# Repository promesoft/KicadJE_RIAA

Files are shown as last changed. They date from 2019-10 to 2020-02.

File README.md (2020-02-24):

# KicadJE_RIAA
RIAA apllifier test

# Status - RIAA installed in stereo setup
## Initial 
| Stage  | Detail | Status |
| --- | --- | --- |
| create material  | sch/pcb | OK  |
| | gerber | OK |
| production  | | OK |
|  | produced | OK |
|  | delivered | OK |
## Preliminary validation
| Test  | Detail | Status |
| --- | --- | --- |
| Initial Inspection | | Chose different RCA |
| Initial Technical Test |  | Different RCA does not match pins |
| Initial Product Test |  | Working - no hum |

## Secondary validation
| Test  | Detail | Status |
| --- | --- |--- |
| Product Test |  | |
| Product Test |  |  |
| Quality | | |
| Quality | | |
| Long Term Product Test |  |  |
| Power Draw |  | 

## Errata
### Errata -
1 - RCA footprint wrong (flip gnd and right)

2 - V-GND 2 does not have resistor balance - only LED indicator as input

3 - C107, C109, C111, C112 should either not be mounted or significantly smaller (10nF ?)

4 - U302B needs an 18k to GND on pin 5

## Issues and Notes
### 

# Pictures

# Inspiration

http://audio.engineeringvista.com/AudioKits/Phono-1/Design/Part6.htm

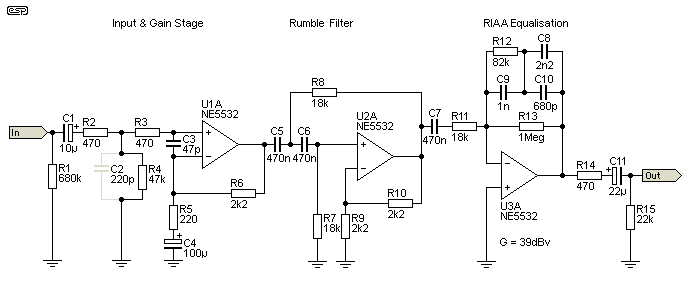
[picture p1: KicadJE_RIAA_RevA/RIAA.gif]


http://sound.whsites.net/project25.htm

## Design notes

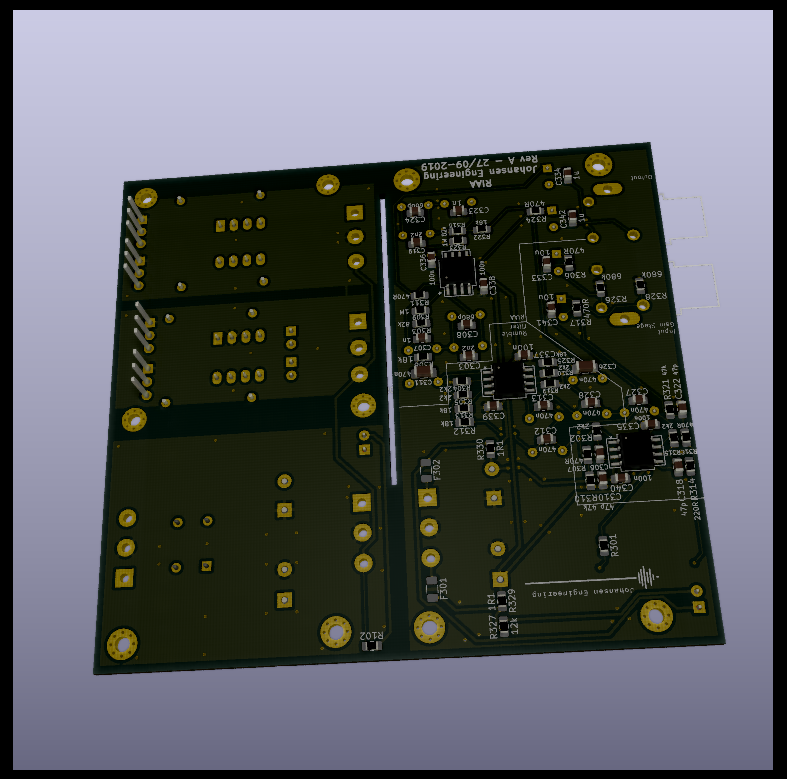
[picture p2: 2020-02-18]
KicadJE_RIAA_RevB/KicadJE_RIAA_bottom.png

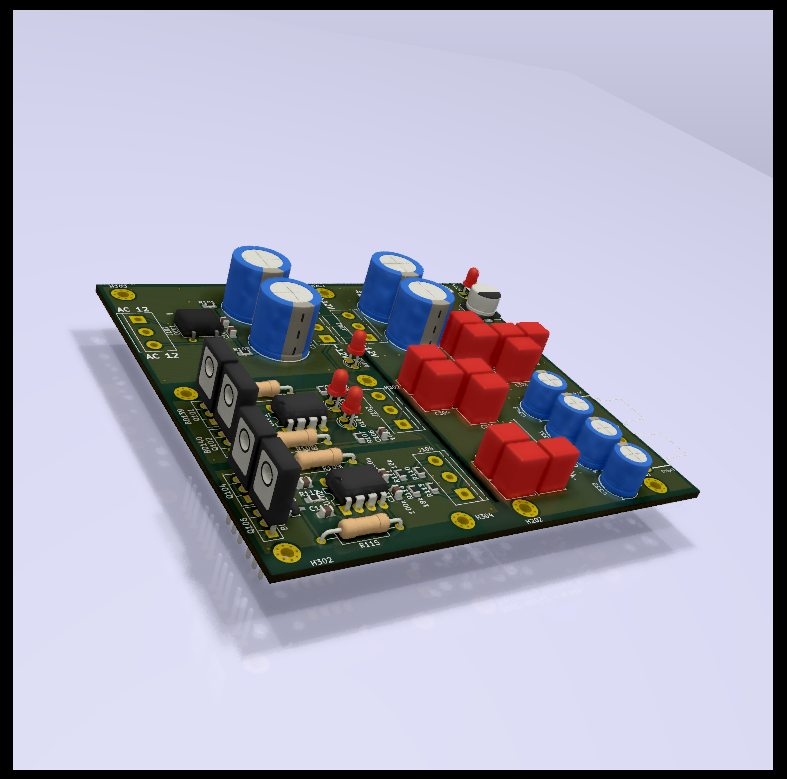
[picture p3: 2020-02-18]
KicadJE_RIAA_RevB/KicadJE_RIAA_top.png

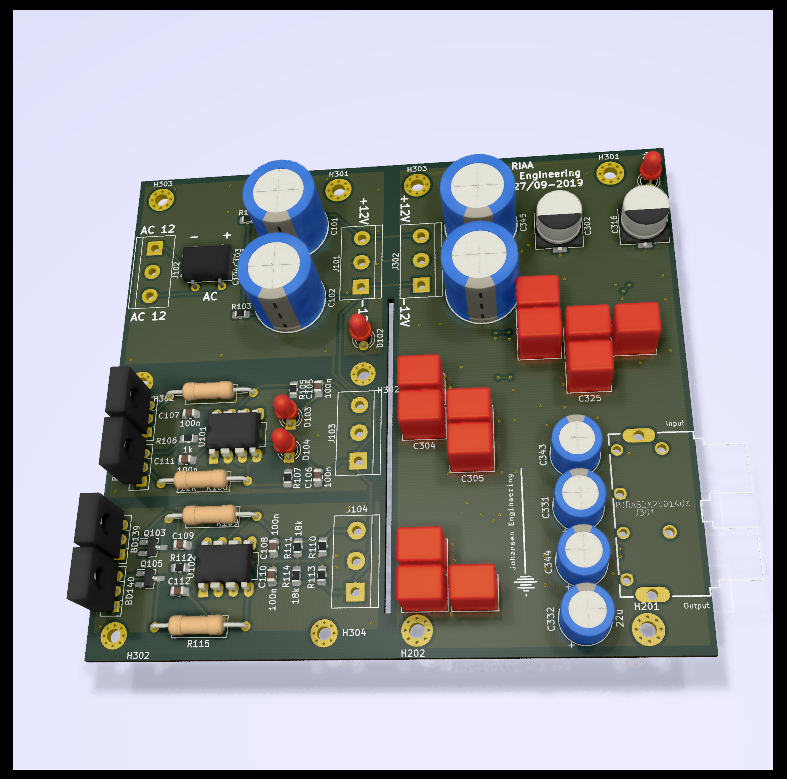
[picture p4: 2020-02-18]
KicadJE_RIAA_RevB/KicadJE_RIAA_top2.png

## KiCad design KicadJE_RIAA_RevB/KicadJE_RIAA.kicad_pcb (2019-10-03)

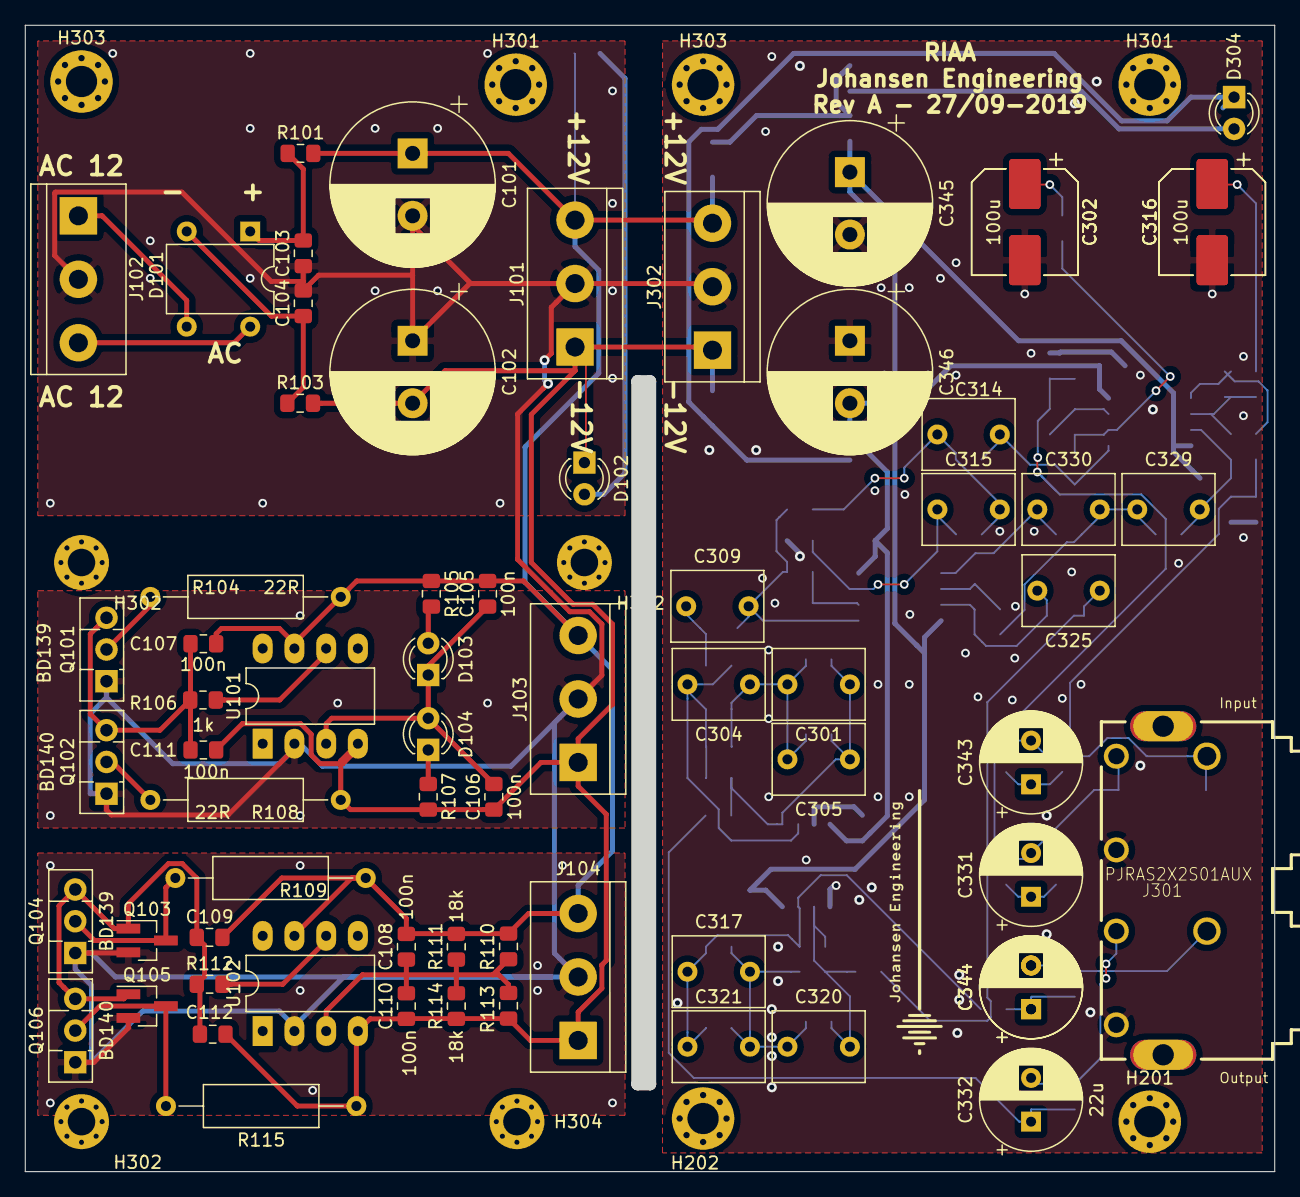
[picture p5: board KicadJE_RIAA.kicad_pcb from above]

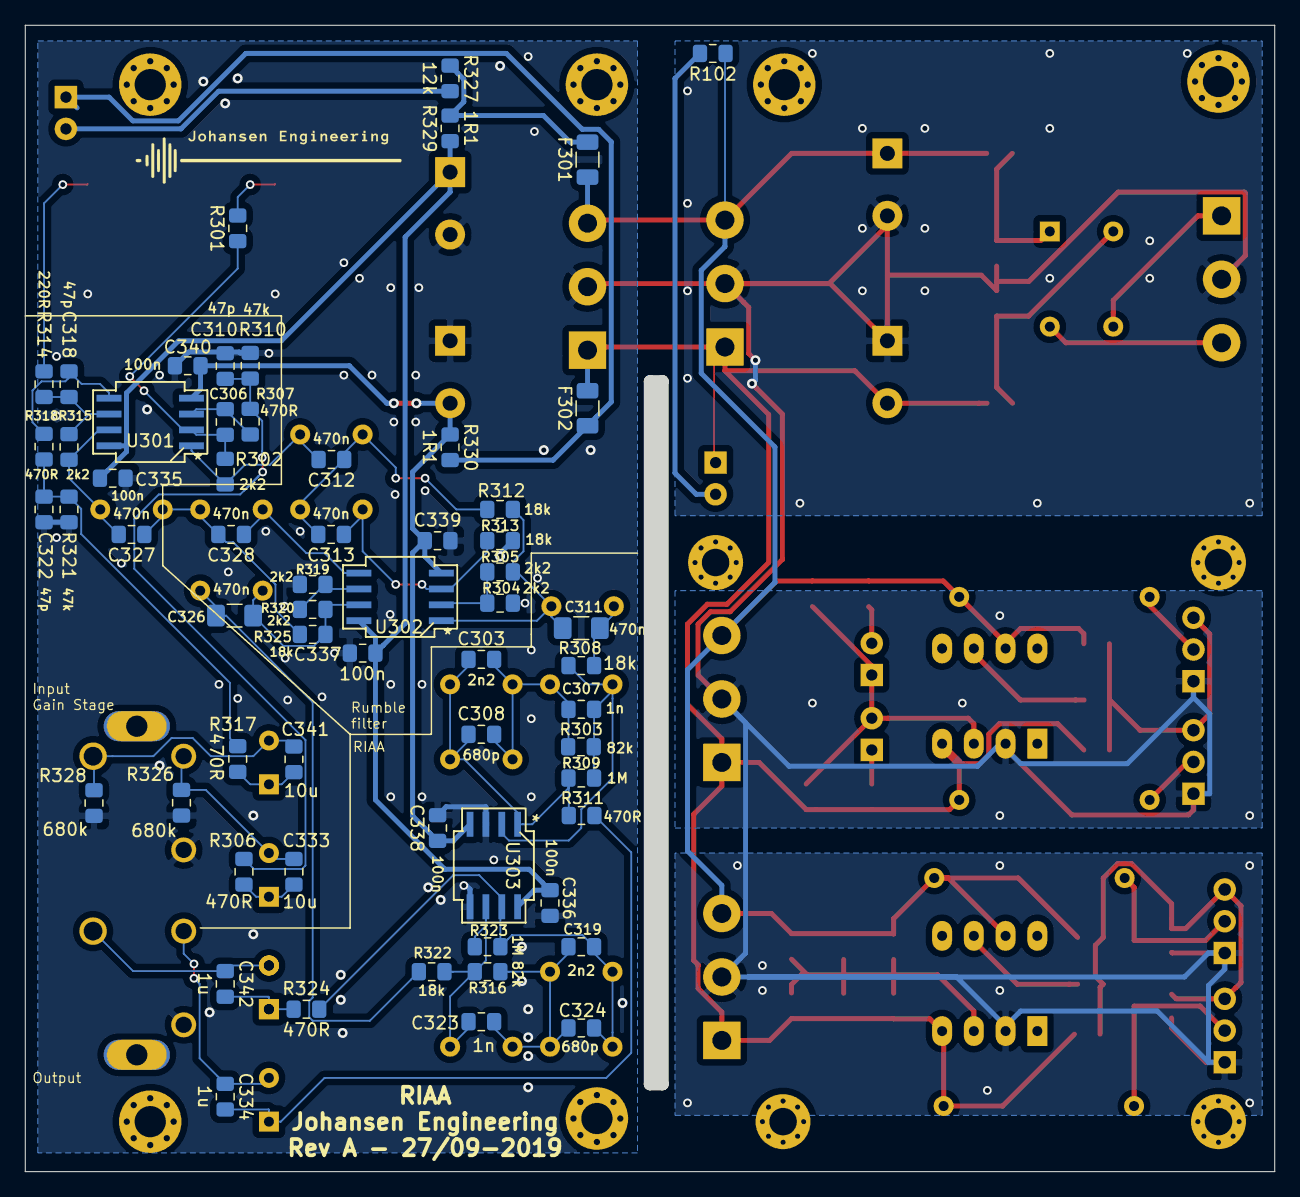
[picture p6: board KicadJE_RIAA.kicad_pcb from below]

Board: 2 copper layers, 100.0 x 91.8 mm, 140 parts (62 on the bottom side), 59 nets.

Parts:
C101, C102, C345, C346: 470u; CP_Radial_D13.0mm_P5.00mm
C103, C104, C105, C106, C107, C108, C109, C110, C111, C112, C335, C336, C337, C338, C339, C340: 100n; C_0805_2012Metric_Pad1.15x1.40mm_HandSolder
C301, C317: 2n2_THT; C_Rect_L7.2mm_W5.5mm_P5.00mm_FKS2_FKP2_MKS2_MKP2
C302, C302#2, C316, C316#2: 100u; CP_Elec_8x6.5
C303, C319: 2n2; C_0805_2012Metric_Pad1.15x1.40mm_HandSolder
C304, C320: 1n_THT; C_Rect_L7.2mm_W5.5mm_P5.00mm_FKS2_FKP2_MKS2_MKP2
C305, C321: 680p_THT; C_Rect_L7.2mm_W5.5mm_P5.00mm_FKS2_FKP2_MKS2_MKP2
C306, C310, C318, C322: 47p; C_0805_2012Metric_Pad1.15x1.40mm_HandSolder
C307, C323: 1n; C_0805_2012Metric_Pad1.15x1.40mm_HandSolder
C308, C324: 680p; C_0805_2012Metric_Pad1.15x1.40mm_HandSolder
C309, C314, C315, C325, C329, C330: 470n_THT; C_Rect_L7.2mm_W5.5mm_P5.00mm_FKS2_FKP2_MKS2_MKP2
C311, C326: 470n; C_1206_3216Metric_Pad1.42x1.75mm_HandSolder
C312, C313, C327, C328: 470n; C_0805_2012Metric_Pad1.15x1.40mm_HandSolder
C331, C343: 10u; CP_Radial_D8.0mm_P3.50mm
C332, C344, C344#2: 22u; CP_Radial_D8.0mm_P3.50mm
C333, C341: 10u; C_0805_2012Metric_Pad1.15x1.40mm_HandSolder
C334, C342: 1u; C_0805_2012Metric_Pad1.15x1.40mm_HandSolder
D101: DF08M; Diode_Bridge_DIP-4_W7.62mm_P5.08mm
D102, D103, D104, D304: LED; LED_D3.0mm
F301, F302: Polyfuse; Fuse_1206_3216Metric
H201, H202, H301, H301#2, H303, H303#2: 2,5mm; MountingHole_2.5mm_Pad_Via
H302, H302#2, H302#3, H304: 2,2mm; MountingHole_2.2mm_M2_Pad_Via
J101, J102, J103, J104, J302: Conn_01x03; TerminalBlock_bornier-3_P5.08mm
J301: PJRAS2X2S01AUX; PJRAS2X2S01AUX_RCA
Q101, Q104: BD139; TO-126-3_Vertical
Q102, Q106: BD140; TO-126-3_Vertical
Q103: MMBT2222A; SOT-23_Handsoldering
Q105: MMBT2907A; SOT-23_Handsoldering
R101, R103, R329, R330: 1R1; R_0805_2012Metric_Pad1.15x1.40mm_HandSolder
R102, R327: 12k; R_0805_2012Metric_Pad1.15x1.40mm_HandSolder
R104, R108, R109, R115: 22R; R_Axial_DIN0309_L9.0mm_D3.2mm_P15.24mm_Horizontal
R105, R107: 10k; R_0805_2012Metric_Pad1.15x1.40mm_HandSolder
R106, R112: 1k; R_0805_2012Metric_Pad1.15x1.40mm_HandSolder
R110, R113: 22k; R_0805_2012Metric_Pad1.15x1.40mm_HandSolder
R111, R114, R308, R312, R313, R322, R325: 18k; R_0805_2012Metric_Pad1.15x1.40mm_HandSolder
R301, R314: 220R; R_0805_2012Metric_Pad1.15x1.40mm_HandSolder
R302, R304, R305, R315, R319, R320: 2k2; R_0805_2012Metric_Pad1.15x1.40mm_HandSolder
R303, R316: 82k; R_0805_2012Metric_Pad1.15x1.40mm_HandSolder
R306, R307, R311, R317, R318, R324: 470R; R_0805_2012Metric_Pad1.15x1.40mm_HandSolder
R309, R323: 1M; R_0805_2012Metric_Pad1.15x1.40mm_HandSolder
R310, R321: 47k; R_0805_2012Metric_Pad1.15x1.40mm_HandSolder
R326, R328: 680k; R_0805_2012Metric_Pad1.15x1.40mm_HandSolder
U101, U102: TL071; DIP-8_W7.62mm_LongPads
U301, U302, U303: TL072; AJ_SO-8_5.3x6.2mm_P1.27mm

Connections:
+12V: C335.2, C336.2, C337.2, C345.1, R329.1, U301.8, U302.8, U303.8
-12V: C338.1, C339.1, C340.1, C346.2, R330.1, U301.4, U302.4, U303.4
/+PSU: C101.1, C105.2, C107.2, C108.2, C109.2, J101.3, J103.3, J104.3, J302.3, R101.2, R102.1, R104.1, R105.1, R109.1, R110.1, R111.2, U101.7, U102.7
/-PSU: C102.2, C106.1, C110.1, C111.1, C112.1, D102.1, J101.1, J103.1, J104.1, J302.1, R103.2, R107.2, R108.1, R113.2, R114.1, R115.1, U101.4, U102.4
/AC1: D101.3, J102.1
/AC3: D101.4, J102.3
/BR+: C103.2, D101.1, R101.1
/BR-: C104.1, D101.2, R103.1
GND: C101.2, C102.1, C103.1, C104.2, C302.2, C302#2.2, C310.2, C316.2, C316#2.2, C322.2, C335.1, C336.1, C337.1, C338.2, C339.2, C340.2, C345.2, C346.1, J101.2, J102.2, J103.2, J104.2, J301.1T1, J301.2T1, J302.2, Q101.1, Q102.1, Q103.2, Q104.1, Q105.2, Q106.1, R304.2, R310.1, R313.1, R319.2, R321.1, R326.2, R328.1, U101.2, U102.2, U303.3, U303.5
In_L: C331.1, C333.2, R306.2
In_R: C341.2, C343.1, R317.2
L_GainOut: C312.2, C314.2, R302.1, U301.1
L_Rumble_Out: C309.2, C311.2, R305.1, R312.1, U302.1
unnamed: C105.1, C106.2, D103.1, D104.2, U101.3
unnamed: C107.1, C111.2, Q101.3, Q102.3, R106.1
unnamed: C108.1, C110.2, R110.2, R111.1, R113.1, R114.2, U102.3
unnamed: C109.1, C112.2, Q103.1, Q104.3, Q105.1, Q106.3, R112.1
unnamed: C301.1, C303.1, C305.1, C308.1, R309.1, R311.2, U303.1
unnamed: C301.2, C303.2, C304.1, C305.2, C307.1, C308.2, R303.1
unnamed: C302.1, C302#2.1, R301.2
unnamed: C304.2, C307.2, R303.2, R308.1, R309.2, U303.2
unnamed: C306.1, R301.1, R302.2, U301.2
unnamed: C306.2, R307.1, U301.3
unnamed: C309.1, C311.1, R308.2
unnamed: C310.1, R306.1, R307.2, R310.2
unnamed: C312.1, C313.2, C314.1, C315.2, R312.2
unnamed: C313.1, C315.1, R313.2, U302.3
unnamed: C316.1, C316#2.1, R314.2
unnamed: C317.1, C319.1, C321.1, C324.1, R323.1, R324.2, U303.7
unnamed: C317.2, C319.2, C320.1, C321.2, C323.1, C324.2, R316.1
unnamed: C318.1, R314.1, R315.2, U301.6
unnamed: C318.2, R318.1, U301.5
unnamed: C320.2, C323.2, R316.2, R322.1, R323.2, U303.6
unnamed: C322.1, R317.1, R318.2, R321.2
unnamed: C325.1, C326.1, R322.2
unnamed: C327.1, C328.2, C329.1, C330.2, R325.2
unnamed: C328.1, C330.1, U302.5
unnamed: C331.2, C333.1, J301.2T2, R326.1
unnamed: C332.2, C334.1, J301.1T2
unnamed: C341.1, C343.2, J301.2S, R328.2
unnamed: C342.1, C344.2, C344#2.2, J301.1S
unnamed: D102.2, R102.2
unnamed: D103.2, R105.2
unnamed: D104.1, R107.1
unnamed: D304.1, F302.1, R330.2
unnamed: D304.2, R327.2
unnamed: F301.2, R327.1, R329.2
unnamed: Q101.2, R104.2
unnamed: Q102.2, R108.2
unnamed: Q103.3, Q104.2, R109.2
unnamed: Q105.3, Q106.2, R115.2
unnamed: R106.2, U101.6
unnamed: R112.2, U102.6
unnamed: R304.1, R305.2, U302.2
unnamed: R319.1, R320.2, U302.6
Out_L: C332.1, C334.2, R311.1
Out_R: C342.2, C344.1, C344#2.1, R324.1
R_GainOut: C327.2, C329.2, R315.1, U301.7
R_Rumble_Out: C325.2, C326.2, R320.1, R325.1, U302.7

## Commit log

2019-10-02 Migrated from Ate0Ate
    [KicadJE_RIAA.kicad_pcb, KicadJE_RIAA.sch]
2019-10-03 SCH incl AC driver
    [KicadJE_RIAA.kicad_pcb, KicadJE_RIAA.sch]
2019-10-03 Dual VGND
    [KicadJE_RIAA.sch]
2019-10-03 Footprints for BJT
    [KicadJE_RIAA.sch]
2019-10-03 hopefully it works
    [KicadJE_RIAA.kicad_pcb, KicadJE_RIAA.sch]
2020-02-18 Picture updates and BOM
    [_saved_KicadJE_RIAA.sch]
2020-02-20 Rev B initiated - errata 1-4
    [KicadJE_RIAA-B_Cu.gbr, KicadJE_RIAA-B_Mask.gbr, KicadJE_RIAA-B_Paste.gbr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]
